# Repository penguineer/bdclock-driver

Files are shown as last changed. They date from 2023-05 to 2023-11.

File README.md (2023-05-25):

# Bulbdial Clock Driver board

> Driver Board for the bulbdial clock in [Netz39](https://www.netz39.de)

This is a driver board for the bulbdial clock built by [Yomin](https://github.com/Yomin) in [bdclock](https://github.com/Yomin/bdclock), which is in turn inspired by the bulbdial clock developed at [Evil Mad Scientist Laboratories](https://www.evilmadscientist.com/2009/a-bulbdial-clock/).

## Interface

The driver circuit operates independently and only needs to be fed data when the displayed values should change.

### Input

The circuit has three input controls `DATA`, `CLK` and `COMMIT`.

The data set contains of 3x8 data bits encoding the active LED for each of the three rows (where the order depends on how the rows are connected and only 0 to 11 lead to an illmuniated LED). Any number of bits can be sent, but only the last 24 bits will be stored in the registers.

The `DATA` is stored on the positive `CLK` edge. When all bits are loaded, the actual content is made visible to the drivers with a positive edge on `COMMIT`. For convenience, `CLK` and `COMMIT` can be driven together. In this case, the shift register's content is always one clock ahead of the storage register (see [SN74HC595 datasheet](https://www.ti.com/lit/ds/symlink/sn74hc595.pdf) p. 11).

### Output

The multiplexer is driven by an internal clock generater.

Each clock row is expected to have a common cathode, which will be multiplexed at the set switching frequency.

The line decoder selects one out of 12 LEDs to be active and expects the anodes of the clock LEDs to be connected to the matching output.

To switch a row off, select a value between 12 and 255, as these are ignored. The row will still be part of the multiplexing cycle.

## License

[MIT](LICENSE.txt) © 2023 Stefan Haun and contributors

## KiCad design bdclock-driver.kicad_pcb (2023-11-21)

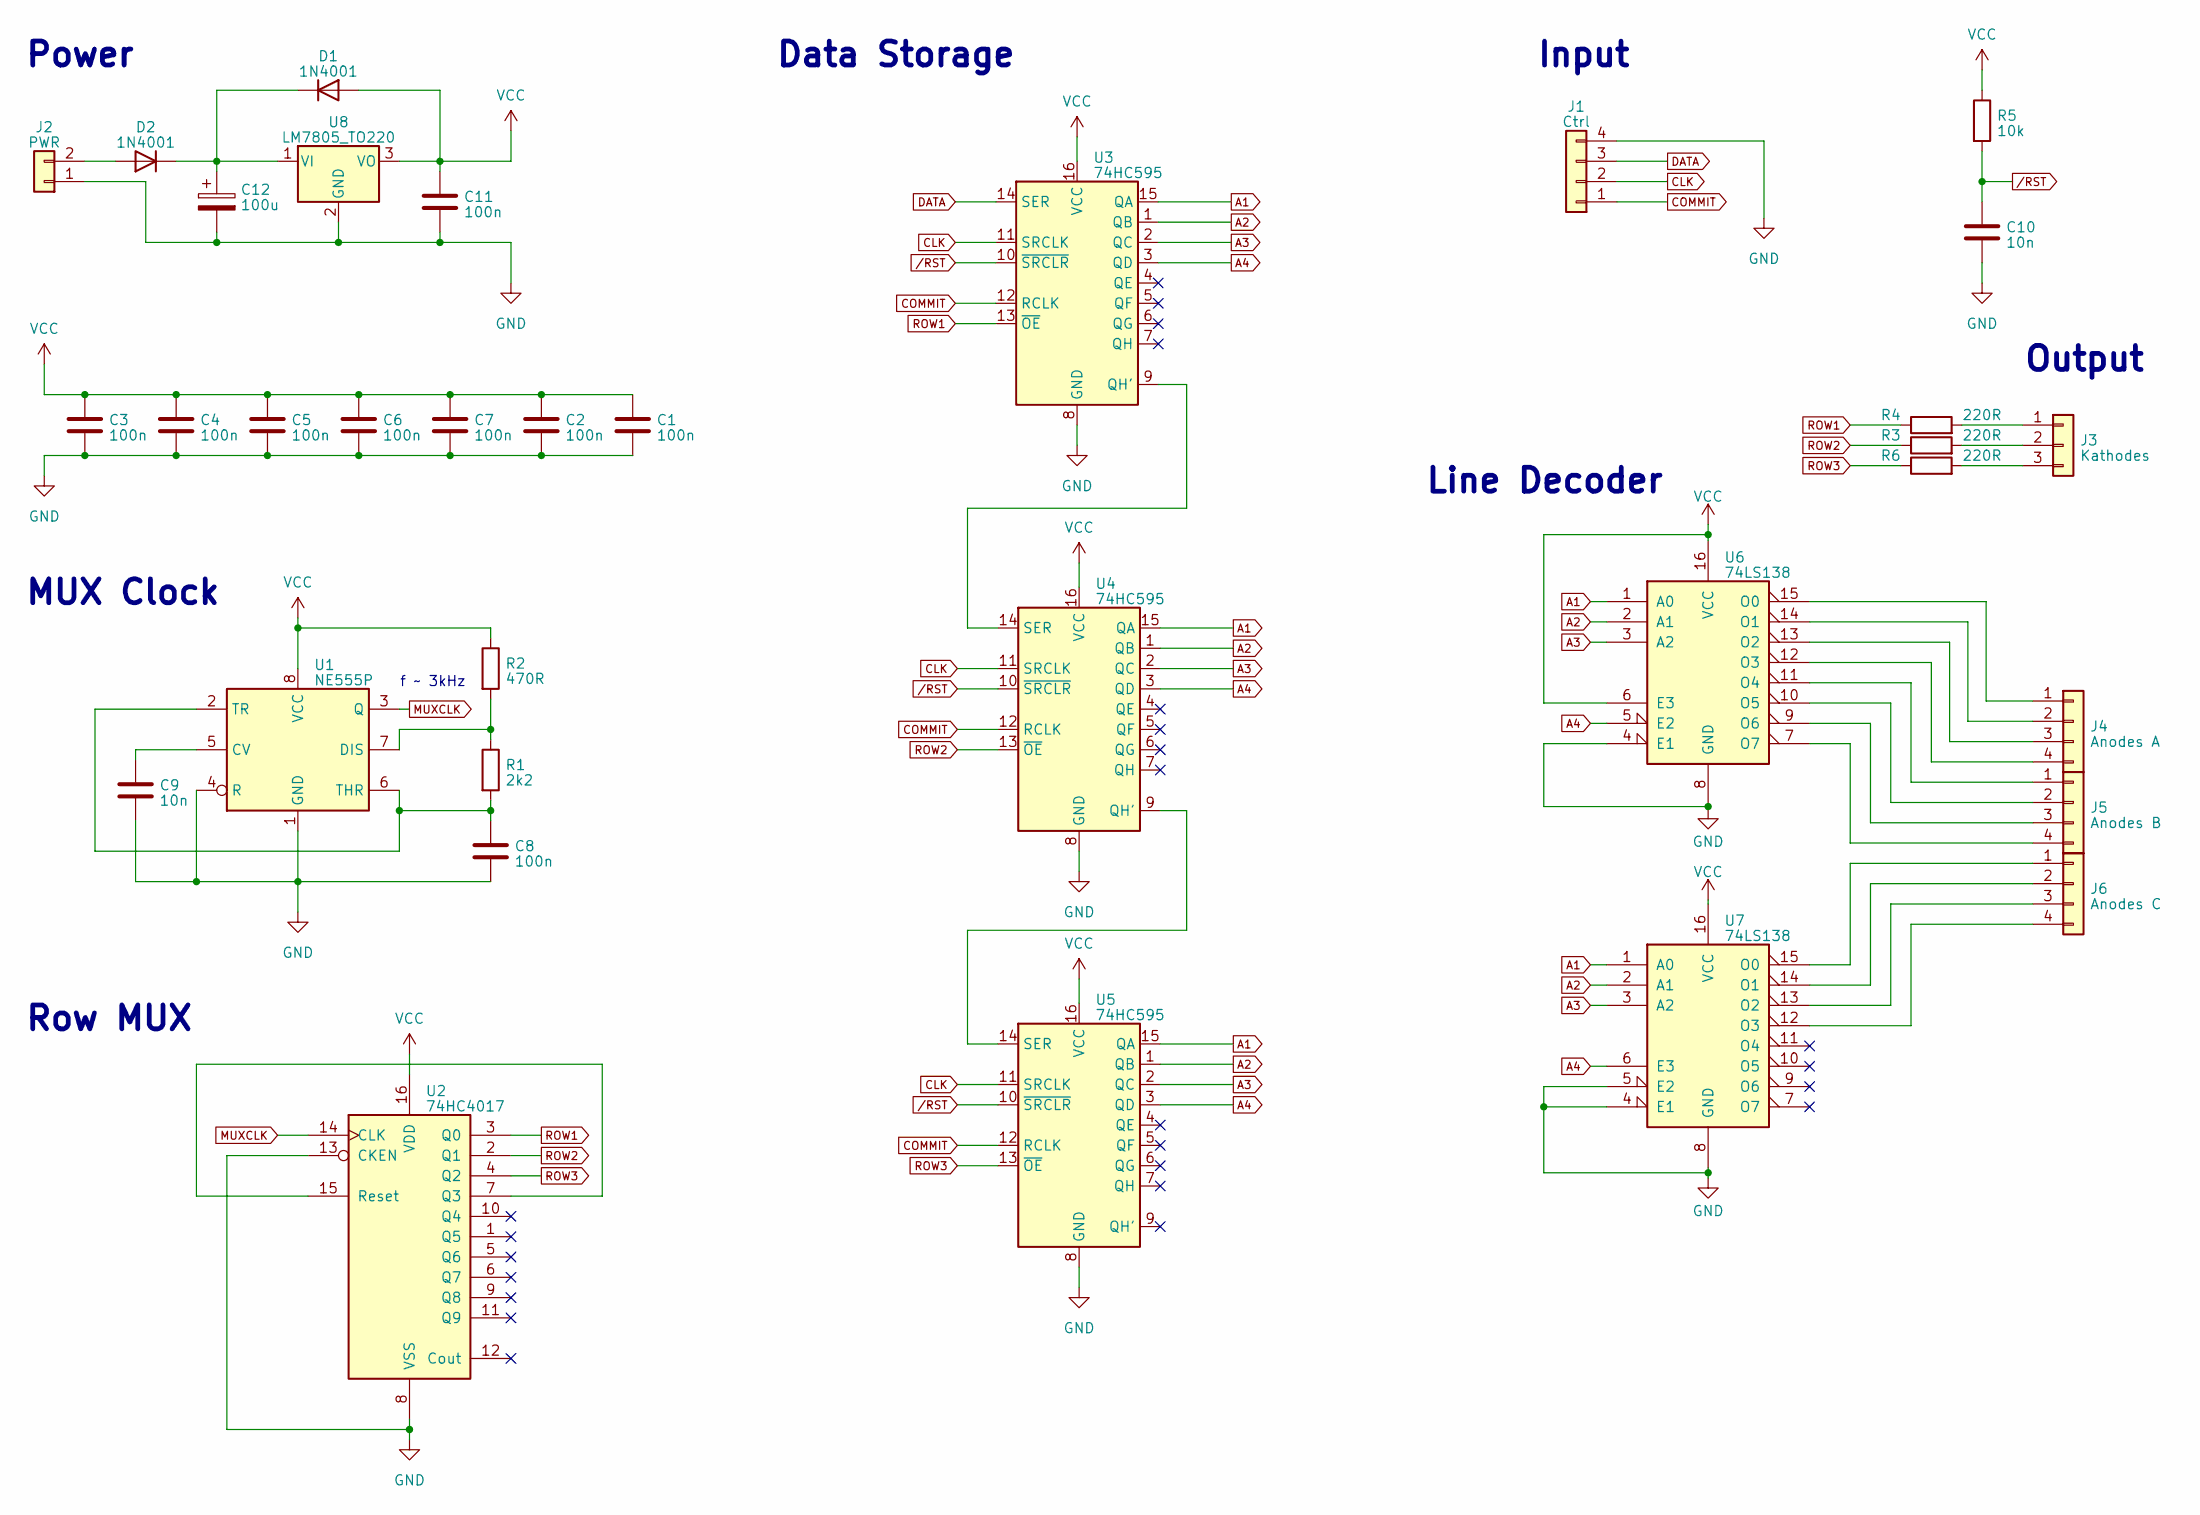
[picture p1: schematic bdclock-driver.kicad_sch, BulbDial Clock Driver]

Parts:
C1, C2, C3, C4, C5, C6, C7, C8, C11: 100n; C_Disc_D4.3mm_W1.9mm_P5.00mm
C9, C10: 10n; C_Disc_D4.3mm_W1.9mm_P5.00mm
C12: 100u; CP_Radial_D6.3mm_P2.50mm
D1, D2: 1N4001; D_DO-41_SOD81_P10.16mm_Horizontal
J1: Ctrl; PinSocket_1x04_P2.54mm_Vertical
J2: PWR; TerminalBlock_Altech_AK300-2_P5.00mm
J3: Kathodes; TerminalBlock_Altech_AK300-3_P5.00mm
J4: Anodes A; TerminalBlock_Altech_AK300-4_P5.00mm
J5: Anodes B; TerminalBlock_Altech_AK300-4_P5.00mm
J6: Anodes C; TerminalBlock_Altech_AK300-4_P5.00mm
R1: 2k2; R_Axial_DIN0207_L6.3mm_D2.5mm_P7.62mm_Horizontal
R2: 470R; R_Axial_DIN0207_L6.3mm_D2.5mm_P7.62mm_Horizontal
R3, R4, R6: 220R; R_Axial_DIN0207_L6.3mm_D2.5mm_P7.62mm_Horizontal
R5: 10k; R_Axial_DIN0207_L6.3mm_D2.5mm_P7.62mm_Horizontal
U1: NE555P; DIP-8_W7.62mm_Socket_LongPads
U2: 74HC4017; DIP-16_W7.62mm_Socket_LongPads
U3, U4, U5: 74HC595; DIP-16_W7.62mm_Socket_LongPads
U6, U7: 74LS138; DIP-16_W7.62mm_Socket_LongPads
U8: LM7805_TO220; TO-220-3_Vertical

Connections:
A1: U3.15 (QA), U4.15 (QA), U5.15 (QA), U6.1 (A0), U7.1 (A0)
A2: U3.1 (QB), U4.1 (QB), U5.1 (QB), U6.2 (A1), U7.2 (A1)
A3: U3.2 (QC), U4.2 (QC), U5.2 (QC), U6.3 (A2), U7.3 (A2)
A4: U3.3 (QD), U4.3 (QD), U5.3 (QD), U6.5 (E2), U7.6 (E3)
CLK: J1.2, U3.11 (SRCLK), U4.11 (SRCLK), U5.11 (SRCLK)
COMMIT: J1.1, U3.12 (RCLK), U4.12 (RCLK), U5.12 (RCLK)
DATA: J1.3, U3.14 (SER)
GND: C1.2, C2.2, C3.2, C4.2, C5.2, C6.2, C7.2, C8.2, C9.2, C10.2, C11.2, C12.2, J1.4, J2.1, U1.1 (GND), U1.4 (R), U2.8 (VSS), U2.13 (CKEN), U3.8 (GND), U4.8 (GND), U5.8 (GND), U6.4 (E1), U6.8 (GND), U7.4 (E1), U7.5 (E2), U7.8 (GND), U8.2 (GND)
MUXCLK: U1.3 (Q), U2.14 (CLK)
unnamed: C12.1, D1.1 (K), D2.1 (K), U8.1 (VI)
unnamed: D2.2 (A), J2.2
unnamed: J3.1, R4.2
unnamed: J3.2, R3.2
unnamed: J3.3, R6.2
unnamed: J4.1, U6.15 (O0)
unnamed: J4.2, U6.14 (O1)
unnamed: J4.3, U6.13 (O2)
unnamed: J4.4, U6.12 (O3)
unnamed: J5.1, U6.11 (O4)
unnamed: J5.2, U6.10 (O5)
unnamed: J5.3, U6.9 (O6)
unnamed: J5.4, U6.7 (O7)
unnamed: J6.1, U7.15 (O0)
unnamed: J6.2, U7.14 (O1)
unnamed: J6.3, U7.13 (O2)
unnamed: J6.4, U7.12 (O3)
unnamed: C9.1, U1.5 (CV)
unnamed: R1.1, R2.2, U1.7 (DIS)
unnamed: C8.1, R1.2, U1.2 (TR), U1.6 (THR)
unnamed: U2.7 (Q3), U2.15 (Reset)
unnamed: U3.9 (QH'), U4.14 (SER)
unnamed: U4.9 (QH'), U5.14 (SER)
ROW1: R4.1, U2.3 (Q0), U3.13 (~OE)
ROW2: R3.1, U2.2 (Q1), U4.13 (~OE)
ROW3: R6.1, U2.4 (Q2), U5.13 (~OE)
VCC: C1.1, C2.1, C3.1, C4.1, C5.1, C6.1, C7.1, C11.1, D1.2 (A), R2.1, R5.1, U1.8 (VCC), U2.16 (VDD), U3.16 (VCC), U4.16 (VCC), U5.16 (VCC), U6.6 (E3), U6.16 (VCC), U7.16 (VCC), U8.3 (VO)
/RST: C10.1, R5.2, U3.10 (~SRCLR), U4.10 (~SRCLR), U5.10 (~SRCLR)

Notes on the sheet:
MUX Clock
Row MUX
Input
Line Decoder
Output
f ~ 3kHz
Data Storage
Power

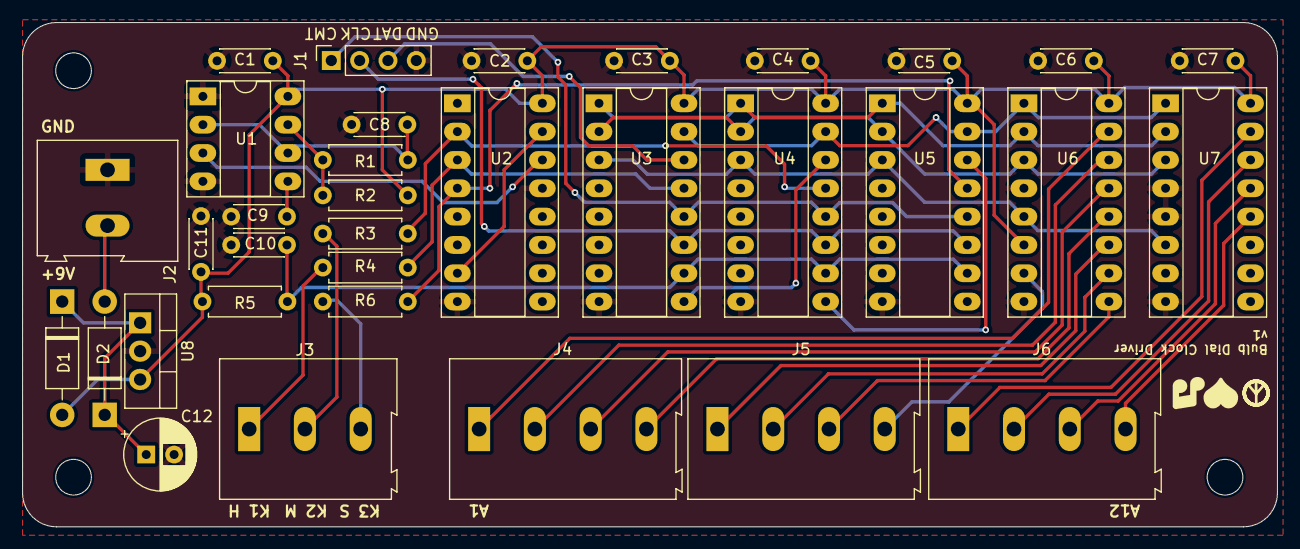
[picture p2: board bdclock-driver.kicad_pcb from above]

Board: 2 copper layers, 112.5 x 45.2 mm, 34 parts (0 on the bottom side), 37 nets.

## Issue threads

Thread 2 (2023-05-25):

:bug: The shift register logic does not work

penguineer, 2023-05-25:
Tying the shift registers together like this does not work :see_no_evil:

~~Replace the 595 ICs by something with a serial out or change the loader logic.~~
Fix the wiring to make use of the 595's cascading logic.

Closed 2023-05-30.

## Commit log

2023-05-16 :see_no_evil: Add gitignore for KiCad projects
2023-05-16 :tada: Add the KiCAD project
    [bdclock-driver.kicad_pcb, bdclock-driver.kicad_sch]
2023-05-23 :sparkles: Add schematic for the decoder/driver
    [bdclock-driver.kicad_sch]
2023-05-25 :bug: Fix the wiring for the 595's cascading logic
    [bdclock-driver.kicad_sch]
2023-05-25 :wrench: Assign missing footprints
    [bdclock-driver.kicad_sch]
2023-05-25 :sparkles: Add PCB layout draft
    [bdclock-driver.kicad_pcb]
2023-08-15 :hammer: Improve PCB layout
    [bdclock-driver.kicad_pcb, bdclock-driver.kicad_sch]
2023-08-20 :art: Finalize the PCB layout
    [bdclock-driver.kicad_pcb, bdclock-driver.kicad_sch]
2023-08-20 :art: Geographical renumeration of all components
    [bdclock-driver.kicad_pcb, bdclock-driver.kicad_sch]
2023-11-21 :art: Place JLCPCB serial number marker and add GND to data connector
    [bdclock-driver.kicad_pcb, bdclock-driver.kicad_sch]
